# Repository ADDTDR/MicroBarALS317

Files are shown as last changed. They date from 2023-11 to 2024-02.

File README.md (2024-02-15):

# ALS317 Bar graph display
## Based on is31fl3730 i2c led driver and ALS317 5 segment led display 
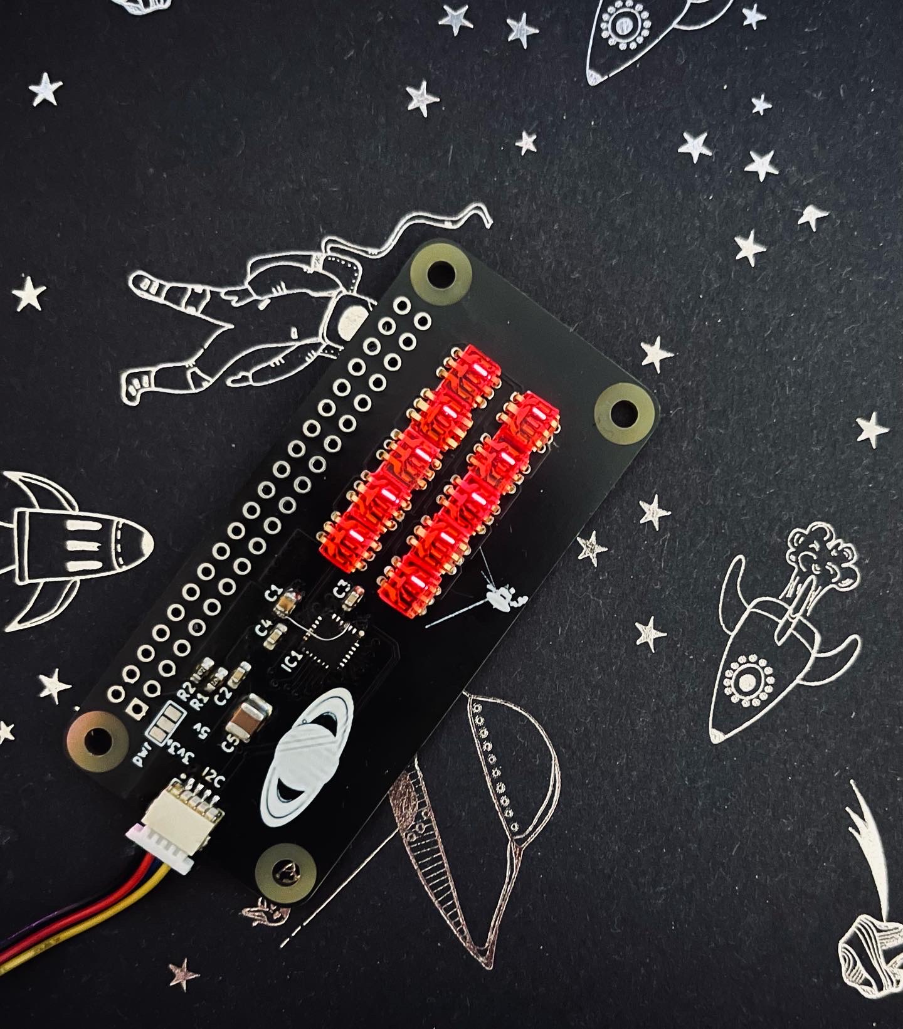
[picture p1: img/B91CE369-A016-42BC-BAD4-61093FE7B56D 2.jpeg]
 
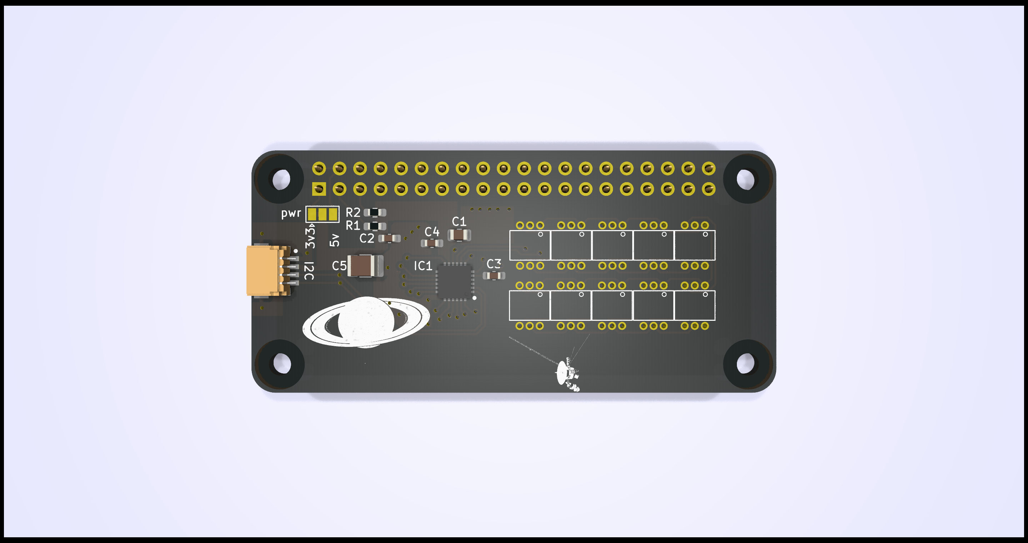
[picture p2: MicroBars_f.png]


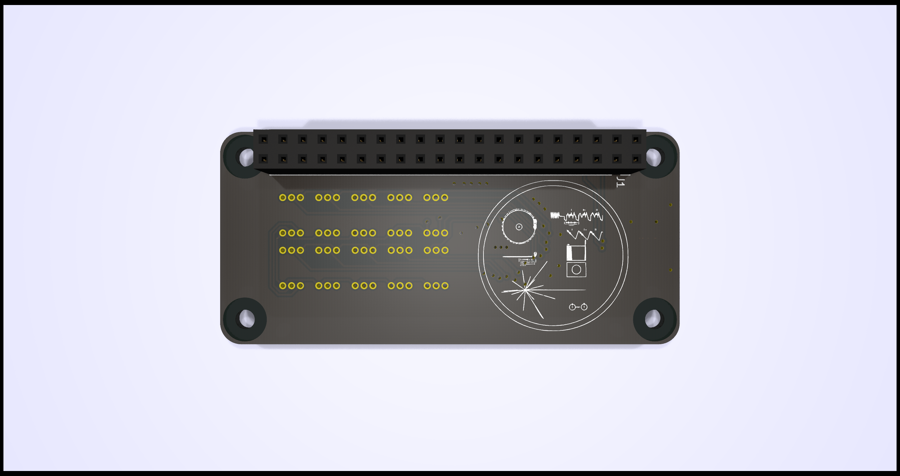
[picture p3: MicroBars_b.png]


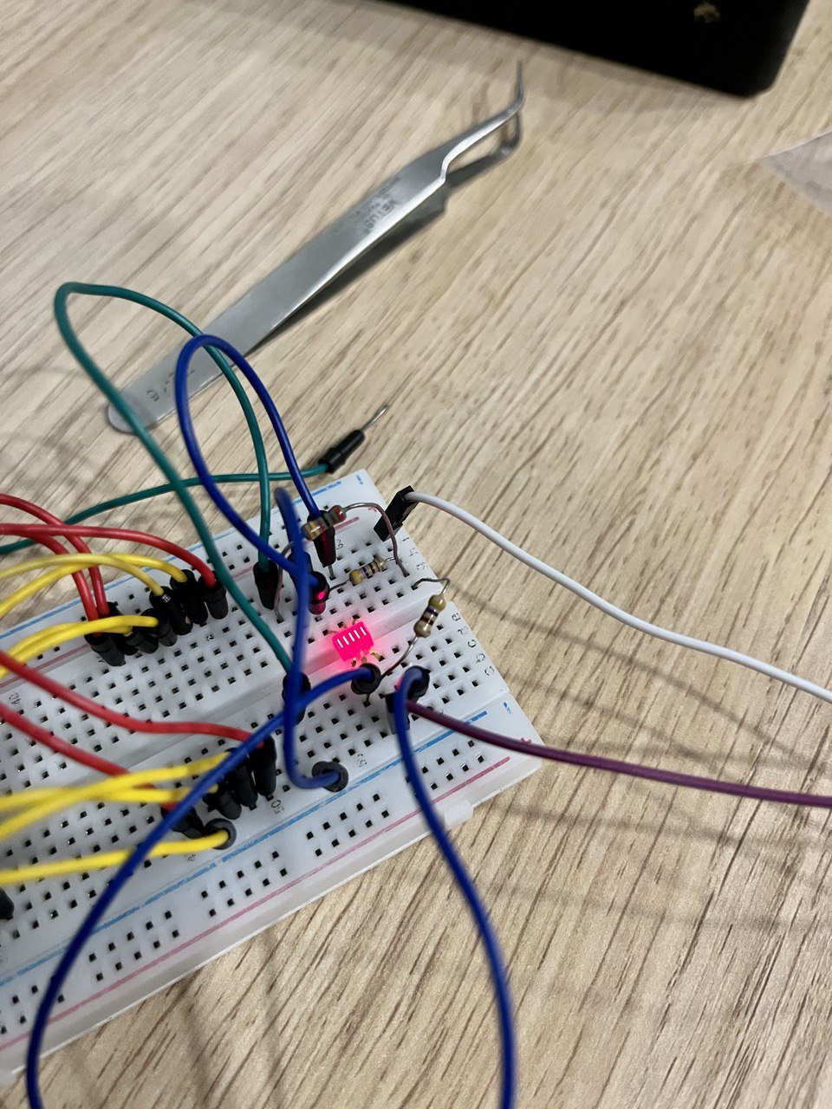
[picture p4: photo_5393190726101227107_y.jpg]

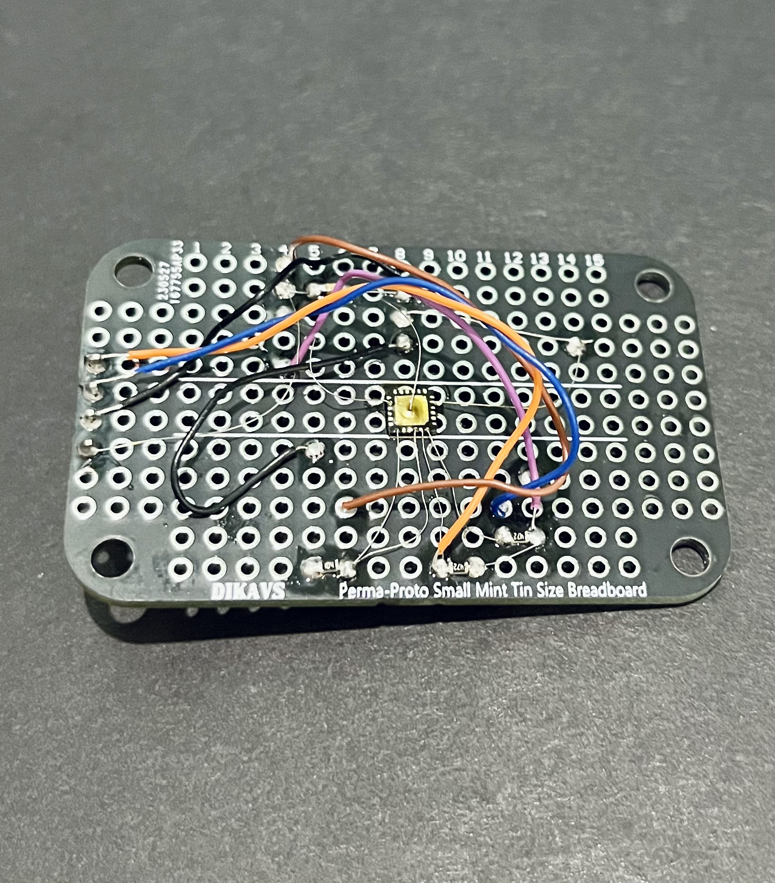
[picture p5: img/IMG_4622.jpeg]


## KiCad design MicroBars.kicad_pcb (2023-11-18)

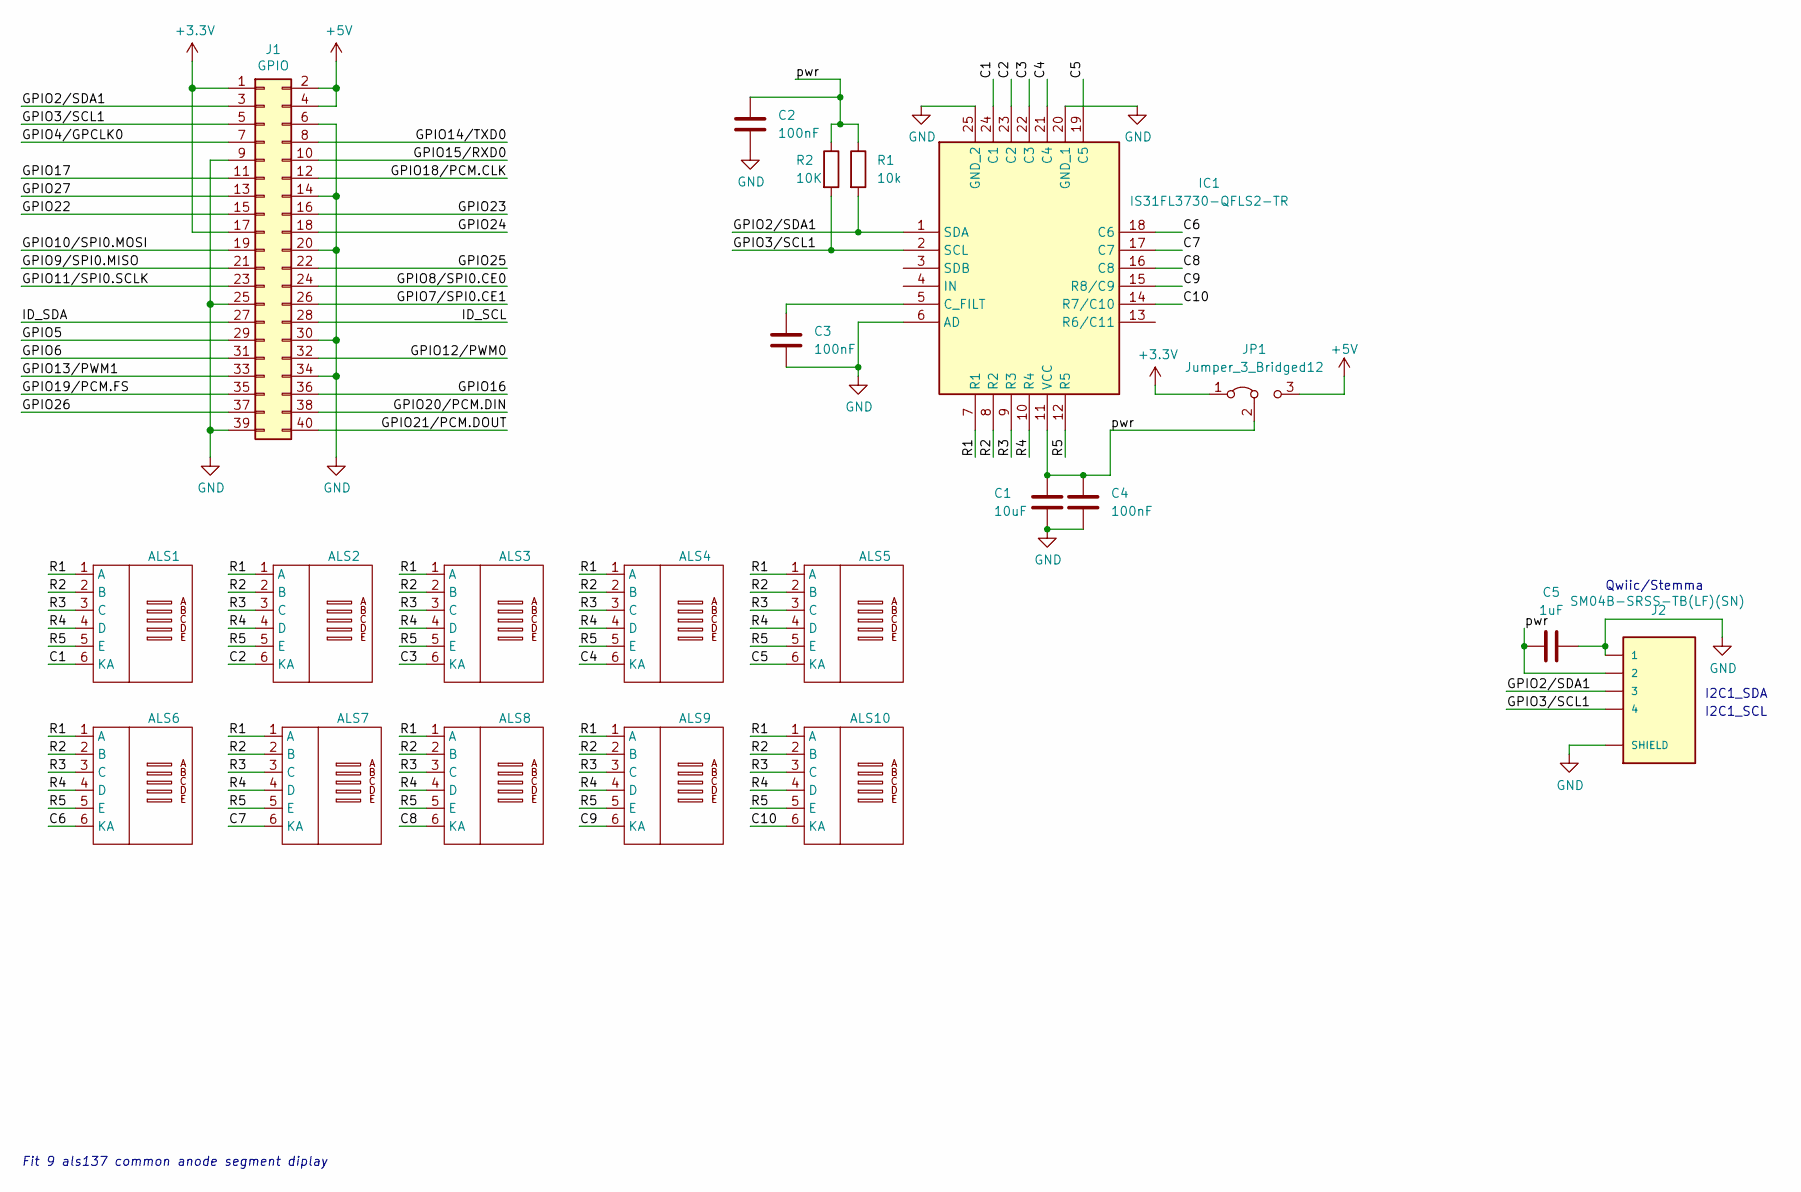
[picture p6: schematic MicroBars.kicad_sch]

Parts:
ALS1, ALS2, ALS3, ALS4, ALS5, ALS6, ALS7, ALS8, ALS9, ALS10: als317
C1: 10uF; C_0805_2012Metric
C2, C3, C4: 100nF; C_0603_1608Metric_Pad1.08x0.95mm_HandSolder
C5: 1uF; C_1210_3225Metric_Pad1.33x2.70mm_HandSolder
IC1: IS31FL3730-QFLS2-TR; QFN50P400X400X80-25N-D; Manufacturer_Part_Number IS31FL3730-QFLS2-TR; Mouser Part Number 870-IS31FL3730QFLS2R
J1: GPIO; PinSocket_2x20_P2.54mm_Vertical
J2: SM04B-SRSS-TB(LF)(SN); JST_SM04B-SRSS-TB(LF)(SN); MPN SM04B-SRSS-TB(LF)(SN); Digi-Key_PN 455-1804-1-ND
JP1: Jumper_3_Bridged12; SolderJumper-3_P1.3mm_Bridged12_Pad1.0x1.5mm
R1: 10k; R_0603_1608Metric_Pad0.98x0.95mm_HandSolder
R2: 10K; R_0603_1608Metric_Pad0.98x0.95mm_HandSolder

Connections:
+3V3: J1.1, J1.17, JP1.1 (A); also elsewhere on the board
+5V: J1.2, J1.4, JP1.3 (B); also elsewhere on the board
/C1: ALS1.6 (KA), IC1.24 (C1)
/C2: ALS2.6 (KA), IC1.23 (C2)
/C3: ALS3.6 (KA), IC1.22 (C3)
/C4: ALS4.6 (KA), IC1.21 (C4)
/C5: ALS5.6 (KA), IC1.19 (C5)
/C6: ALS6.6 (KA), IC1.18 (C6)
/C7: ALS7.6 (KA), IC1.17 (C7)
/C8: ALS8.6 (KA), IC1.16 (C8)
/C9: ALS9.6 (KA), IC1.15 (R8/C9)
/C10: ALS10.6 (KA), IC1.14 (R7/C10)
/GPIO2/SDA1: IC1.1 (SDA), J1.3, J2.3, R1.2
/GPIO3/SCL1: IC1.2 (SCL), J1.5, J2.4, R2.2
/GPIO4/GPCLK0: J1.7
/GPIO5: J1.29
/GPIO6: J1.31
/GPIO7/SPI0.CE1: J1.26
/GPIO8/SPI0.CE0: J1.24
/GPIO9/SPI0.MISO: J1.21
/GPIO10/SPI0.MOSI: J1.19
/GPIO11/SPI0.SCLK: J1.23
/GPIO12/PWM0: J1.32
/GPIO13/PWM1: J1.33
/GPIO14/TXD0: J1.8
/GPIO15/RXD0: J1.10
/GPIO16: J1.36
/GPIO17: J1.11
/GPIO18/PCM.CLK: J1.12
/GPIO19/PCM.FS: J1.35
/GPIO20/PCM.DIN: J1.38
/GPIO21/PCM.DOUT: J1.40
/GPIO22: J1.15
/GPIO23: J1.16
/GPIO24: J1.18
/GPIO25: J1.22
/GPIO26: J1.37
/GPIO27: J1.13
/ID_SCL: J1.28
/ID_SDA: J1.27
/R1: ALS1.1 (A), ALS2.1 (A), ALS3.1 (A), ALS4.1 (A), ALS5.1 (A), ALS6.1 (A), ALS7.1 (A), ALS8.1 (A), ALS9.1 (A), ALS10.1 (A), IC1.7 (R1)
/R2: ALS1.2 (B), ALS2.2 (B), ALS3.2 (B), ALS4.2 (B), ALS5.2 (B), ALS6.2 (B), ALS7.2 (B), ALS8.2 (B), ALS9.2 (B), ALS10.2 (B), IC1.8 (R2)
/R3: ALS1.3 (C), ALS2.3 (C), ALS3.3 (C), ALS4.3 (C), ALS5.3 (C), ALS6.3 (C), ALS7.3 (C), ALS8.3 (C), ALS9.3 (C), ALS10.3 (C), IC1.9 (R3)
/R4: ALS1.4 (D), ALS2.4 (D), ALS3.4 (D), ALS4.4 (D), ALS5.4 (D), ALS6.4 (D), ALS7.4 (D), ALS8.4 (D), ALS9.4 (D), ALS10.4 (D), IC1.10 (R4)
/R5: ALS1.5 (E), ALS2.5 (E), ALS3.5 (E), ALS4.5 (E), ALS5.5 (E), ALS6.5 (E), ALS7.5 (E), ALS8.5 (E), ALS9.5 (E), ALS10.5 (E), IC1.12 (R5)
/pwr: C1.1, C2.1, C4.1, C5.1, IC1.11 (VCC), J2.2, R1.1, R2.1; also elsewhere on the board
GND: C1.2, C2.2, C3.2, C4.2, C5.2, IC1.6 (AD), IC1.20 (GND_1), IC1.25 (GND_2), J1.6, J1.9, J1.14, J1.20, J1.25, J1.30, J1.34, J1.39, J2.1, J2.S1 (SHIELD), J2.S2 (SHIELD)
unnamed: C3.1, IC1.5 (C_FILT)

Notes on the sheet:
Qwiic/Stemma
I2C1_SCL
Fit 9 als137 common anode segment diplay
I2C1_SDA

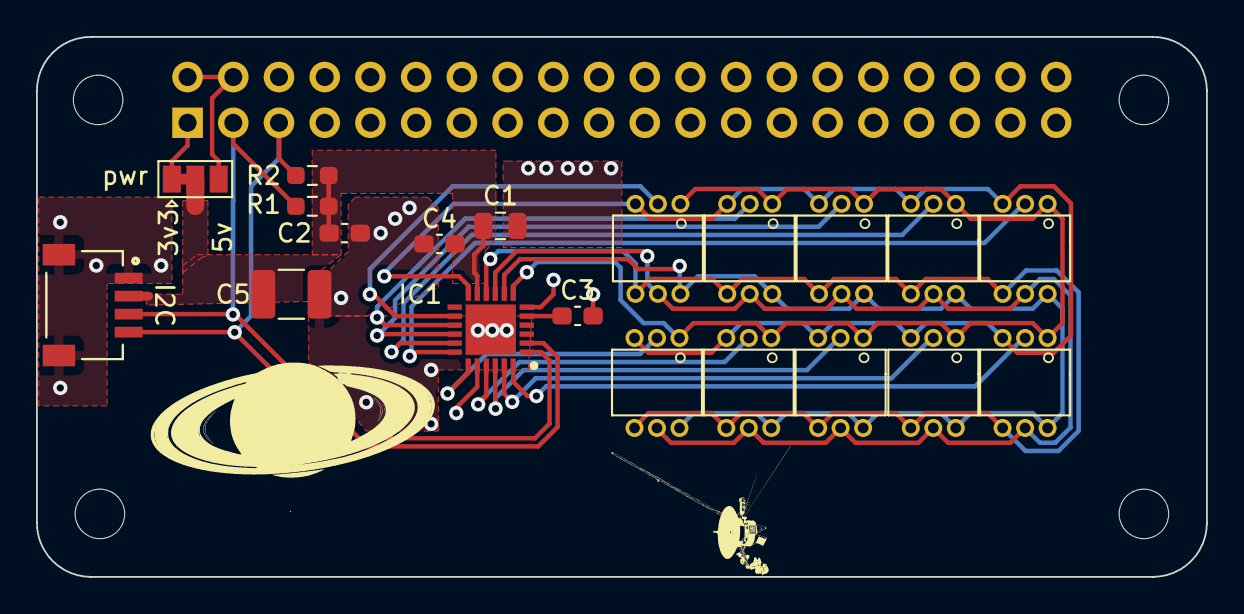
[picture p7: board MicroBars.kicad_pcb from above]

Board: 2 copper layers, 65.0 x 30.0 mm, 21 parts (1 on the bottom side), 22 nets.

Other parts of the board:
pwr: Jumper_3_Bridged12; SolderJumper-3_P1.3mm_Bridged12_Pad1.0x1.5mm

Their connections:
+3V3: pwr.1 (A); also elsewhere on the board
+5V: pwr.3 (B); also elsewhere on the board
/pwr: pwr.2 (C); also elsewhere on the board

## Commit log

2023-11-18 Version 1
    [MicroBars-B_Cu.gbr, MicroBars-B_Mask.gbr, MicroBars-B_Paste.gbr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]
2024-02-03 Add images of the built sample
